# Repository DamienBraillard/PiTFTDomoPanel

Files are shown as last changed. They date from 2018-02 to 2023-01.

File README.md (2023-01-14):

# PiTFTDomoPanel
Raspberry PI + PiTFT based home automation web control panel with screen activated by PIR movement detector

This project was started so that I am able to control some basic functions of my home automation system at home. It uses a RaspberryPi with a 2.8" capacitive touch PiTFT display from Adafruit and a small PIR movement detection module.

The idea is to activate the screen only when movement is detected to avoid useless screen usage and wear when the panel is not in use. The device simply displays a web page from the home automation system.

This projects consists of many parts:
* A 3D box model to house everything
* The list of hardware needed to create the project
* The code that manages the PIR movement detector
* Setup instructions to enable the PiTFT display and setup X to display a web page in kiosk mode

## What does it look like ?
Here are some pictures of the final result:
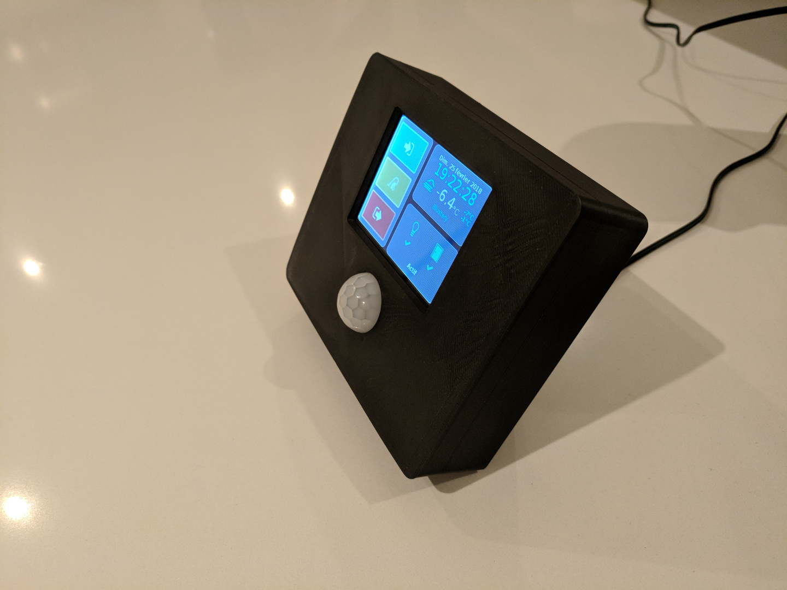
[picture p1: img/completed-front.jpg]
Front view

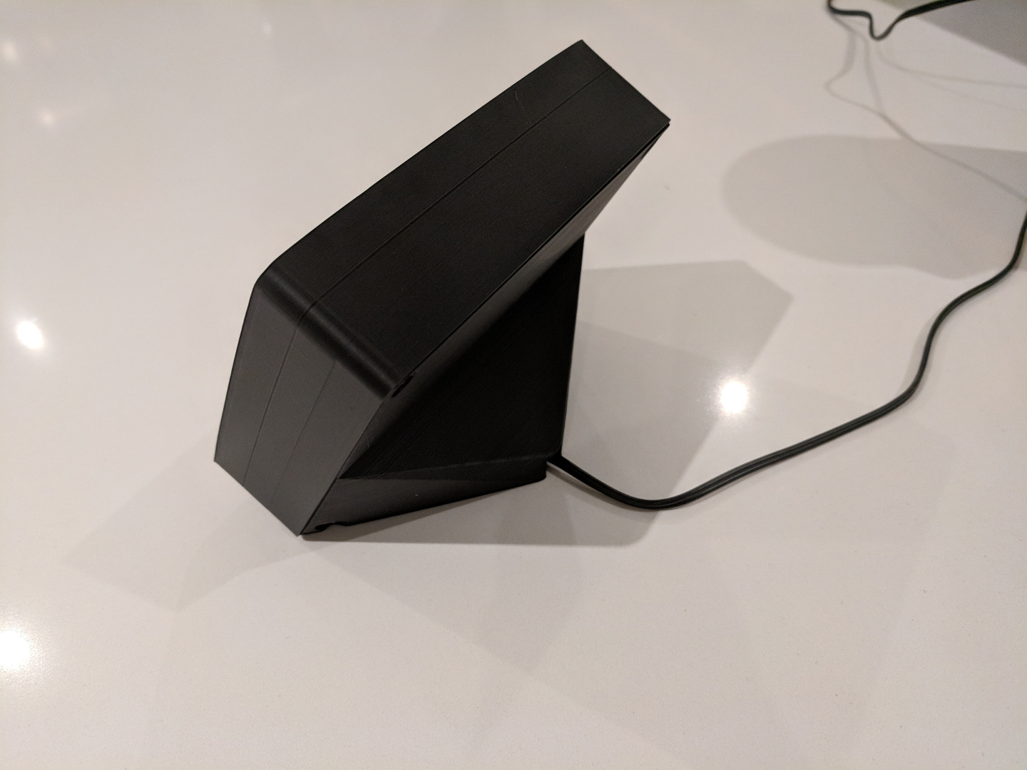
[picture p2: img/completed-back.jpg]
Back view


# Make your own
In the following sections, you will find a detailled description of the steps to make one.

## Bill of materials
To realize this project, the following components are required:
* A Raspberry PI B+ (2 or 3)
* An Adafruit PiTFT PLUS 2.8" capacitive touch TFT screen
  ([Adafruit link](https://www.adafruit.com/product/2423))
* A PIR sensor module from Adafruit or any other vendor ([Adafruit link](https://www.adafruit.com/product/189))
* A 3D printer or access to one
* Some Screws:
    * 4x M4x10mm (25mm max) with conic head to close the enclosure
    * 4x M3x5mm to tighten the PiTFT to the enclosure
    * 2x M2x5mm to tighten the PIR to the enclosure

## Wiring
The only thing to wire manually is the PIR sensor to the Raspberry Pi.
One problem to face is that the PiTFT hat connects on the Raspberry Pi taking all the GPIO pins.
The solution to that problem is to use the second male connector at the back of the PiTFT.

For that, I soldered a piece of ribbon cable to which I soldered individual cutable headers but feel free to use any other mean of wiring.
You can also solder the three cables to the PiTFT header and the RPI header. I't more definitive
but, less cumbersome than creating a custom cable like I did. If I make another one, I will take the
soldering to header approach !

To give you an idea, the PIR has three pins, Ground, VCC (+5V) and output.
Ground goes to one of the Ground pins of the Pi, VCC to a +5V pin and Output goes
to the GPIO4 of the Raspberry Pi.

To help you figure out the wiring, here is a picture of the final wiring result:
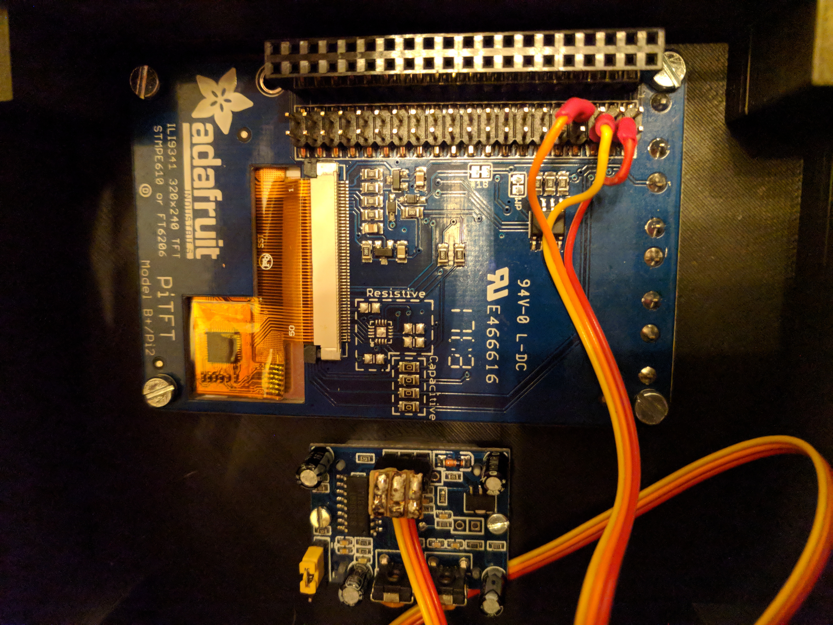
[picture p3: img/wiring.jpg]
Wiring


I cannot include a Fritzing schema here becaus it's impossible to find a schematic where the back header is visible. But it's pretty obvious from the picture above.
On the picture the collor of the cables correspond to:
* Read: VCC
* Orange: Output
* Yellow: Ground

## Installation of the RPi base system and the PiTFT
### Install raspbian
First of all, start with a fresh raspbian lite installation.
This project is based on Raspbian stretch.
Go to the [raspbian homepage](https://www.raspberrypi.org/downloads/raspbian/), download the "lite" image and follow the installation guide.

Don't forget to enable ssh and/or finetune your installation with the `raspi-config` utility.

### Configure the PiTFT hardware
Connect to the Raspberry using SSH.

Edit the file **/boot/config.txt**
```
#> sudo nano /boot/config.txt
```

Enable SPI and I2C interfaces by uncommenting the following lines. The former is required to send data to the TFT display, the later to handle the touch screen.
```
dtparam=spi=on
dtparam=i2c_arm=on
```

Then enable the overlay for the PiTFT display by adding the following lines at the end of the file.
The first line sets the communication speed to 32Mhz, reduce to 16Mhz if your screen behaves strangly. It also sets the refresh speed to 25 frames per seconds which is enough in our case.
The second line performs a screen rotation of 270° then adapts the touch screen so that it matches the display. It maches the layout of the TFT in the box created for the project but feel free to tweak this.
```
# PiTFT overlay
dtoverlay=pitft28-capacitive,speed=32000000,fps=25
dtoverlay=pitft28-capacitive,rotate=270,touch-swapxy,touch-invy
```
It is important to use two lines because there is a maximum file length of something linke 79 characters and there are too many parameters to fit within this line length limit.

Last remark, the available orientation options are:
* rotate       : Rotation of the screen (0, 90, 180 or 270)
* touch-swapxy : Swaps the X and Y axis of the touch screen
* touch-invx   : Inverses the direction of the X axis (Y axis if swapped)
* touch-invy   : Inverses the direction of the Y axis (X axis if swapped)

Save and close nano 

### Display the boot console on the PiTFT at startup
Here we will modify the kernel boot parameters so that the boot messages are displayed on the PiTFT during boot. This will also give you a login prompt in case something goes really wrong.

Edit the file **/boot/cmdline.txt**
```
#> sudo nano /boot/cmdline.txt
```

Append the following options to the startup command line (after the **bootwait** argument)
```
fbcon=map:10 fbcon=font:VGA8x8
```

Save and close nano

Reboot your Raspberry Pi and enjoy the boot messages:
```
#> sudo reboot
```

You should see the boot screen upon reboot and end up with a prompt once the boot has completed.

## Installation and configuration of the X11 server
Now that we have the TFT with it's framebuffer working, we can attack installing and setting up the application.

We will use the following software:
* X11: will be responsible for the graphical environment.
* matchbox: a minimal lightweight window manager.
* nodm: a minimal window manager
* xset: a X tool that can be used to tweak stuff like the screen saver
* unclutter: a X tool that allows to hide the mouse cursor.

### Install the X11 server and configure the PiTFT framebuffer

Install the basic x11 packages with the matchbox windows manager a browser and the nodm lightweight desktop manager.
```
#> sudo apt install x11-xserver-utils xinit matchbox nodm unclutter
```

Create a new file **/usr/share/X11/xorg.conf.d/99-pitft.conf**:
```
#> sudo nano /usr/share/X11/xorg.conf.d/99-pitft.conf
```

Enter the following content:
```
Section "Device"
  Identifier "Adafruit PiTFT"
  Driver "fbdev"
  Option "fbdev" "/dev/fb1"
EndSection
```
An important point is the use of "/dev/fb1" here. The PiTFT will settle on the framebuffer 1 as framebuffer 0
is already taken by the HDMI output.

Just for safety, ensure that the file **/usr/share/X11/xorg.conf.d/99-fbturbo.conf** does not exists. If it does, just move it to your home folder for backup.
```
sudo mv /usr/share/X11/xorg.conf.d/99-fbturbo.conf ~
```
You are free to delete it.

## Install the frontend Python application
The application will be installed in the home directory of the user `pi`.

### Install the application files

First, create a new directory for the program and copy the python application:
```
#> mkdir ~/domo-panel
```

Copy the files from the `frontend` git folder in `~/domo-panel`

Create the python virtual environment:
```
#>sudo apt install -y python3-venv libsdl2-2.0-0 libsdl2-ttf-2.0-0 libsdl2-image-2.0-0
#>python3 -m venv ~/domo-panel//venv
#>~/domo-panel/venv/bin/pip3 install -r ~/domo-panel//requirements.txt
```

### Setup nodm display manager

Edit the **/etc/default/nodm** file
```
#> sudo nano /etc/default/nodm
```

Ensure that the following values are set as below
```
NODM_ENABLED=true
NODM_USER=pi
```

### Create the X11 session startup file

Next step will tell the system what should be done when the graphical environment
starts. This is the place where the browser will be started.

Create the file **/home/pi/.xsession** and open it using nano

```
#> nano ~/.xsession
```

And enter the following content:
``` bash
#!/bin/bash

# disable the DPMS (Energy Star) features
xset -dpms

# disable the screen saver
xset s off

# hide the mouse cursor when not moving
unclutter -idle 0 &

# Run the window manager !
matchbox-window-manager -use_titlebar no &

# Starts the application
~/domo-panel/venv/bin/python ~/domo-panel/main.py
```

Then change the permissions of the file to **700**:
```
#> chmod 700 /.xsession
```

### Enable boot to the graphical environment
As the lite version of Raspbian has been installed, it will boot to console by default.
In order to boot into graphical mode, it's necessary to tell **systemctl** to boot
to the graphical target.

To do so, type in the following command: 
```
#> sudo systemctl set-default graphical.target
```

Everything should be working now. The next thing to do is to reboot.
The raspberry should reboot in graphical mode with the Midori browser displaying
the web page in full screen mode.
```
#> sudo reboot
```

## Activating the PIR sensor to activate the screen when a movement is detected
One thing left to do is install and enable the python script that manages the IR movement detector. When movement is detected, the script will enable the script for a configurable duration and then disable it again.

### Installing required python and packages
The script requires **python3.x** and the **RPi.GPIO** python module.
Make sure these are installed using the following command:
```
#> sudo apt install python3 python3-rpi.gpio
```

### Installing the python script and the startup service
It's better to install the python script at a usual location for executables.

Copy the content of he `src/pir` folder to the `/home/pi` home directory of your Raspberry Pi.

Make the **install.sh** script executable and run it:
```
#> chmod -v 755 install.sh
#> ./install.sh
```

This script does the following:
1. Creates the folder */usr/local/bin/pirscreen**
1. Copies the **pirscreenmanager.py** to that folder
1. Makes the copied script executable
1. Copies the **pirscreen.sh** RC script to the **/etc/init.d** folder.
1. Eakes the copied RC script executable
1. Enables the script to run at boot

By default:
* The screen stays on for 30 seconds
* The X display is ':0'
* Log file located at **/tmp/pirscreenmanager.log**

To change any of these options, the **DAEMON_OPTS** variable in the **/etc/init.d/pirscreen.sh** file must be modified.
To do so, edit the file with nano and change it's content:
```
#> sudo nano /etc/init.d/pirscreen.sh
```

## Printing the case and assembling
The case that can be seen in the images is available in the `src/enclosure` folder.

The two `.stl` files are provided ready to print.

### Modification of the model before printing
In the case where you whish to change the model, open the source `.scad` with [OpenScad](http://www.openscad.org/).

The file starts with all parameters and two modules, one for each part of the box:
* front_part : The module to render the front part of the box.
* back_part  : The module to render the back part of the box.

Before exporting the STL file, don't forget to leave only the part to export uncommented at the end of the file and do a render (F6).

### Assembling
To assemble the electronics and the 3D printed box, some extra screws are needed:
    * 4x M4x10mm (25mm max) with conic head
    * 4x M3x5mm 
    * 2x M2x5mm

To assemble:
1. Separate the PiTFT board from the Raspberry Pi.
1. Screw the PiTFT to the front of the case using the four M3 screws.
1. Screw the PIR to the front of the case using the M2 screws.
1. Plug the MicroUSB power to the PI
1. Reassemble the Raspberry Pi on top of the PiTFT board
1. Power up to check that everything still works.
1. Pass the power cable in the channel at the bottom of the back of the case.
1. Assemble the back and the front using the four M4 screws.

Here are pictures of the final assembly:
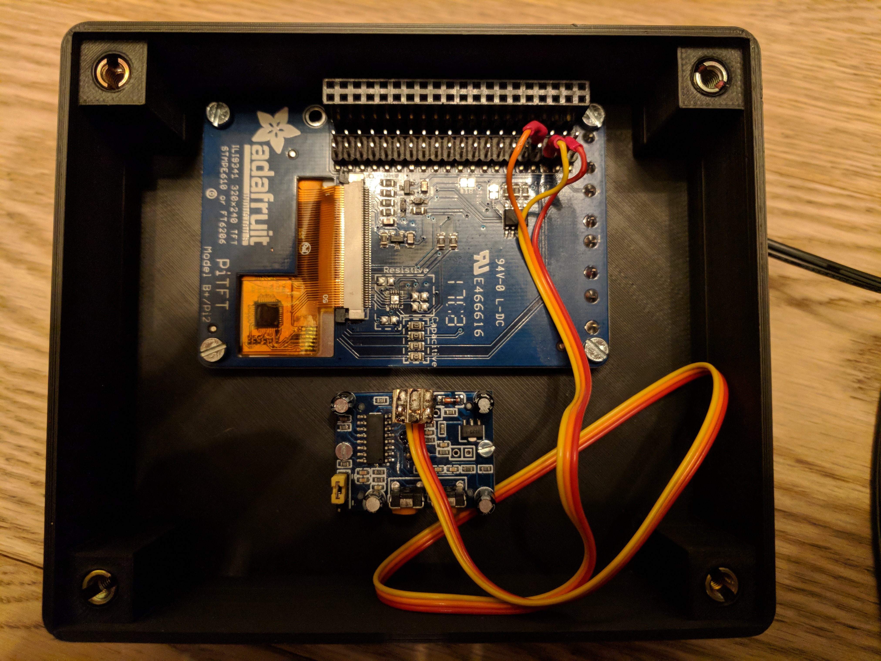
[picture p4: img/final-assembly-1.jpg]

Front view

Note that on the pictures, I used special metal bolts fused into the plastic. I removed these from the 3D model because they don't bring extra value and are quite hard to find. So don't panic if your model does not have these. In the revised version, the screws go directly into the plastic !

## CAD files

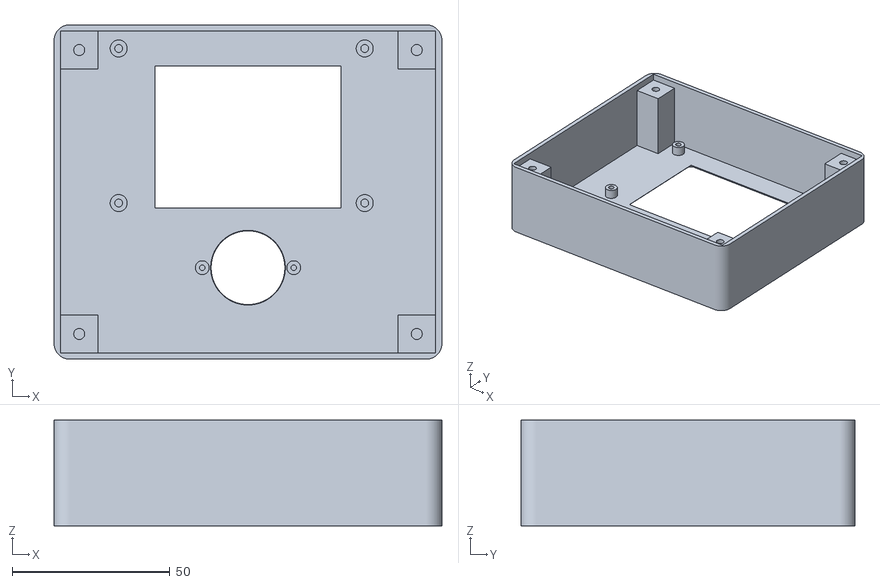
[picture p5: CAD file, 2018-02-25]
src/enclosure/PiTFTDomoPanel-Front.stl
123.0 x 106.0 x 33.5

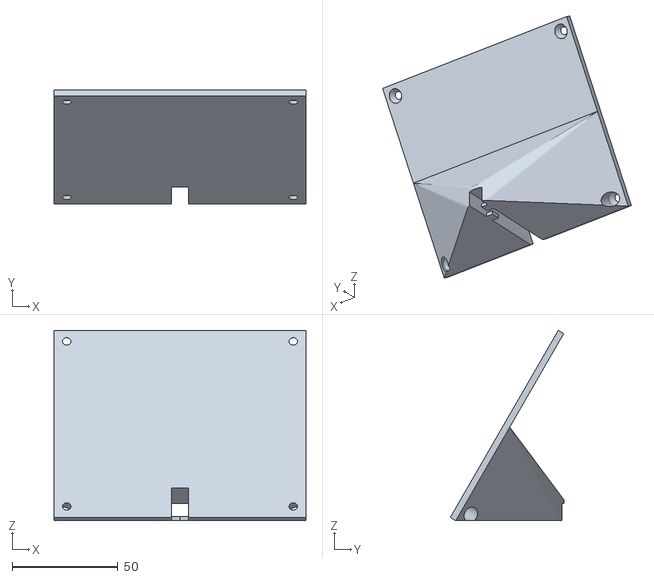
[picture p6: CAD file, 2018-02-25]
src/enclosure/PiTFTDomoPanel-Back.stl
119.0 x 53.6 x 89.8

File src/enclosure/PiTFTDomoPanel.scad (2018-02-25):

/*******************************************************************************
* ENCLOSURE FOR RASPBERRY PI + PITFT + PIR SENSOR
* ------------------------------------------------------------------------------
* Copyright Damien Braillard, Switzerland
* ------------------------------------------------------------------------------
* Bill of materials:
*   - 4 M3 with 5mm long thread screws to hold the screen
*   - 2 M2 with 5mm long thread screws to hold the PIR
*   - 4 M4 with conic head to tighten he back part with the front part
*******************************************************************************/

// =============================================================================
// Defines all the measurements
// =============================================================================
tft_width           = 59;   // Width of the TFT display area
tft_height          = 45;   // Height of the TFT display area
tft_thick           =  4.5; // Thickness of the TFT display module (without board)
tft_pcb_thick       =  1;   // Thickness of the TFT PCB
tft_margin_left     = 11;   // Left distance from RPi board edge to TFT display area edge
tft_margin_right    = 15;   // Right distance from RPi board edge to TFT display area edge
tft_margin_top      =  9;   // Top distance from RPi board edge to TFT display area edge
tft_margin_bottom   =  3;   // Bottom distance from RPi board edge to TFT display area edge
tft_screw_diam      =  3;   // Diameter of the TFT attachement screw thread
tft_screw_height    =  5;   // Length of the TFT attachement screw thread
tft_hole_offsets    = [     // Offsets [X,Y] of holes in TFT board relative to top-left corner
                       [3.5, 3.5],
                       [81.5, 3.5],
                       [3.5, 52.5],
                       [81.5, 52.5]
                     ];

pi_width            = 85;   // Width of the RPi board
pi_height           = 56;   // Height of the RPi board
pi_thick            = 19;   // Thickness of the PI + TFT board (without the display)

pir_lens_diam       = 23;   // Diameter of the PIR lens
pir_lens_thick      =  3.5; // Thickness of the PIR lens base
pir_pcb_thick       =  1.5; // Thickness of the PIR board
pir_screw_height    =  5;   // Length of the PIR attachement screws thread
pir_screw_diam      =  2;   // Diameter of the PIR attachement screws thread
pir_hole_offsets    = [     // Offsets(X,Y) of PIR holes relative to PIR center (space between holes = 29mm)
                        -14.5,
                        14.5
                      ];
pir_height          = 24;   // Height of the PIR module
pir_width           = 33;   // Width of the PIR module
pir_spacing         =  5;   // Distance between the PIR and the PI board

screw_thread_diam   =  4;   // Diameter of the body screw threads
screw_head_diam     =  7;   // Diameter of the body screw head
screw_head_thick    =  2.5; // Thickness of the body screw head
screw_pillar_side   = 12;   // Side of the square pillars that hold the bolts.

cable_diam          =  4;   // Diameter of the USB cable

body_top_margin     =  2;   // Clearance on top of the last component
body_bottom_margin  = 20;   // Clearance before the firtst compnent can be found
body_back_margin    = 5;    // Clearance at the back of the PI board
body_angle          = 60;   // Inclinaison angle of the body in degrees

back_walls          =  3;   // Thickness of the back plate + stand walls
front_walls         =  2;   // Thickness of the front panel walls 
body_in_width       = tft_width + (2 * 30);        // 28mm + margin each side of the TFT
body_in_height      = pi_height + pir_height + body_bottom_margin + body_top_margin;
body_in_thick       = pi_thick + tft_thick + body_back_margin;

echo("Body In Width =",body_in_width);
echo("Body In Height =",body_in_height);
echo("Body In Thick =",body_in_thick);

$fn=100;

// Calculated values
_pi_top          = body_in_height - body_top_margin;
_pi_left         = ((body_in_width - tft_width) / 2) - tft_margin_right; // Correct because screen flipped down
_tft_top         = body_in_height - body_top_margin - tft_margin_top;
_tft_left        = (body_in_width - tft_width)/2;
_pir_center_top  = body_in_height - body_top_margin - pi_height - pir_spacing - pir_height / 2;
_pir_center_left = body_in_width / 2;

// Utiliy modules
module rounded_cube(size, r=5) {

  linear_extrude(height=size[2])
  hull() {
    translate([r, r])
      circle(r=r);
    translate([size[0]-r, r])
      circle(r=r);
    translate([r, size[1]-r])
      circle(r=r);
    translate([size[0]-r, size[1]-r])
      circle(r=r);    
  }
  
}

// Renders the front part
module front_part() {

    difference() {
      translate([-front_walls, -front_walls, -front_walls])
        rounded_cube([body_in_width+front_walls*2, body_in_height+front_walls*2, body_in_thick+front_walls+back_walls]);
      
      // Main opening
      cube([body_in_width, body_in_height, body_in_thick+back_walls+1]);
      
      // Hole for PIR sensor
      translate([_pir_center_left, _pir_center_top, 0])
        sphere(d=pir_lens_diam*1.03);
      
      // Hole for screen
      translate([_tft_left, _tft_top-tft_height, -(front_walls*2-.005)])
        minkowski() {
          cube([tft_width, tft_height, front_walls]);
          cylinder(r1=front_walls, r2=0, h=front_walls);
        } 
    }

    // TFT fixation holes
    for(i = tft_hole_offsets) {
      translate([_pi_left + pi_width - i[0], _pi_top - i[1], 0]) {
        difference() {
          cylinder(d=tft_screw_diam+2.4, h=tft_thick-.4);
          translate([0, 0, tft_thick+tft_pcb_thick-tft_screw_height-.5])
            cylinder(d=tft_screw_diam-.5, h=tft_thick+1);
        }
      }
    }
    
    // PIR fixation holes
    for(i = pir_hole_offsets) {
      translate([_pir_center_left + i, _pir_center_top, 0])
        difference() {
          cylinder(d=pir_screw_diam+2.4, h=pir_lens_thick-.4);
          translate([0, 0, pir_lens_thick+pir_pcb_thick-pir_screw_height-.5])
            cylinder(d=pir_screw_diam-.25, h=pir_screw_height+1);
        }      
    }
    
    // Screw holders
    for(x = [0, body_in_width-screw_pillar_side], y = [0, body_in_height-screw_pillar_side]) {
      translate([x, y, 0])
      difference() {
        cube([screw_pillar_side, screw_pillar_side, body_in_thick]);
        translate([screw_pillar_side/2, screw_pillar_side/2, 0])
          cylinder(d=screw_thread_diam-.5, h=body_in_height+2);
      }
    }
  
}

// Renders the back part
module back_part() {
  base_depth = cos(body_angle)*body_in_height;
  difference() {
    union() {
      // Main plate
      rotate([body_angle, 0, 0]) { 
        cube([body_in_width, body_in_height, back_walls]);        
      }
      
      // Foot
      hull() {
        translate([body_in_width/2, base_depth-10, 0])
          cylinder(d=20, h=10);
        rotate([body_angle, 0, 0]) {
          cube([body_in_width, body_in_height/2, back_walls]);
        }
      }
    }
    
    // == SCREW HOLES == 
    rotate([body_angle, 0, 0]) { 
      for(x = [screw_pillar_side/2, body_in_width-screw_pillar_side/2],
          y = [screw_pillar_side/2, body_in_height-screw_pillar_side/2]) {
        translate([x, y, -.005]) {
          cylinder(d=screw_thread_diam, h=back_walls+.01);
          cylinder(d1=screw_head_diam+.5, d2=screw_thread_diam, h=screw_head_thick+.5);
          translate([0, 0, -30])
            cylinder(d=screw_head_diam+.5, h=30.001);
        }
      }    
    }

    // == CABLE OPENING ==
    channel_width = cable_diam*2;
    peg_center    = base_depth*3/4;
    peg_thick     = 2;
    peg_len       = 5;
    peg_spacing   = cable_diam;
    {
      // Plate Cable opening
      rotate([body_angle, 0, 0])
      translate([(body_in_width-channel_width)/2, -.1, -20])
        cube([channel_width, cable_diam*4+.1, back_walls+20.1]);
      // Foot channel
      translate([(body_in_width-channel_width)/2, 0, -.01]) {
        // Main channel
        translate([0, 0, peg_thick-.1])
          cube([channel_width, base_depth, cable_diam+2.1]);
        // Front main opening 
        cube([channel_width, peg_center-peg_len-peg_spacing/2, peg_thick]);
        // Front peg
        translate([0, peg_center-peg_len-peg_spacing/2-.1, -.1])
          cube([channel_width/2, peg_len+.2, peg_thick+.1]);
        // Space between pegs 
        translate([0, peg_center-peg_spacing/2, 0])
          cube([channel_width, peg_spacing, peg_thick]);
        // Back peg
        translate([channel_width/2, peg_center+peg_spacing/2-.1, -.1])
          cube([channel_width/2, peg_len+.2, peg_thick+.1]);
        // Back main opening
        translate([0, peg_center+peg_len+peg_spacing/2, 0])
          cube([channel_width, base_depth-peg_center-peg_len-peg_spacing/2, peg_thick]);
      }
    }
  }  
}
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

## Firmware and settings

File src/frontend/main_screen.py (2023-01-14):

import pygame
from pygame import Rect
import pygame_gui
import pygame_gui.elements as elements
from screen import Screen
from communicator import Communicator, HouseMode
from typing import Union, Type
from datetime import datetime


class MainScreen(Screen):
    def __init__(self, surface: pygame.Surface, communicator: Communicator):
        super().__init__(surface)
        self.__communicator = communicator

    def _on_create_controls(self, manager: pygame_gui.UIManager):
        # panels
        elements.UIPanel(relative_rect=Rect((0, 0), (320, 60)),
                         starting_layer_height=1,
                         manager=manager)
        # elements.UIPanel(relative_rect=Rect((0, 70), (110, 170)),
        #                  starting_layer_height=1,
        #                  manager=manager)
        elements.UIPanel(relative_rect=Rect((120, 70), (200, 170)),
                         starting_layer_height=1,
                         manager=manager)

        # Top labels
        self.__time_label = elements.UILabel(relative_rect=Rect((5, 5), (115, 50)),
                                             text="-",
                                             manager=manager,
                                             object_id="@time-label")
        self.__date_labels = [
            elements.UILabel(relative_rect=Rect((130, 6), (60, 16)),
                             text="-",
                             manager=manager,
                             object_id="@date-label"),
            elements.UILabel(relative_rect=Rect((130, 22), (60, 16)),
                             text="-",
                             manager=manager,
                             object_id="@date-label"),
            elements.UILabel(relative_rect=Rect((130, 38), (60, 16)),
                             text="-",
                             manager=manager,
                             object_id="@date-label")
        ]

        self.__temp_label = elements.UILabel(relative_rect=Rect((195, 5), (120, 50)),
                                             text="°C",
                                             manager=manager,
                                             object_id="@temp-label")

        # Mode buttons
        self.__present_button = elements.UIButton(relative_rect=Rect((0, 70), (110, 50)),
                                                  text='Présent',
                                                  manager=manager,
                                                  object_id="@button_present")
        self.__away_button = elements.UIButton(relative_rect=Rect((0, 130), (110, 50)),
                                               text='Absent',
                                               manager=manager,
                                               object_id="@button_away")
        self.__cleaning_button = elements.UIButton(relative_rect=Rect((0, 190), (110, 50)),
                                                   text='Ménage',
                                                   manager=manager,
                                                   object_id="@button_cleaning")

        # Status for doors and lights
        self.__lights_icon_pos = (151, 90)
        self.__doors_icon_pos = (246, 90)

        self.__lights_label_ok = elements.UILabel(relative_rect=Rect((130, 160), (85, 30)),
                                                  text="-",
                                                  manager=manager,
                                                  object_id="@status-label-ok")
        self.__lights_label_warning = elements.UILabel(relative_rect=Rect((130, 160), (85, 30)),
                                                       text="-",
                                                       manager=manager,
                                                       object_id="@status-label-warning")
        self.__lights_label_error = elements.UILabel(relative_rect=Rect((130, 160), (85, 30)),
                                                     text="-",
                                                     manager=manager,
                                                     object_id="@status-label-error")

        self.__doors_label_ok = elements.UILabel(relative_rect=Rect((225, 160), (85, 30)),
                                                 text="-",
                                                 manager=manager,
                                                 object_id="@status-label-ok")
        # self.__doors_label_warning = elements.UILabel(relative_rect=Rect((225, 160), (85, 30)),
        #                                               text="-",
        #                                               manager=manager,
        #                                               object_id="@status-label-warning")
        self.__doors_label_error = elements.UILabel(relative_rect=Rect((225, 160), (85, 30)),
                                                    text="-",
                                                    manager=manager,
                                                    object_id="@status-label-error")

        # Current mode label
        self.__mode_label_present = elements.UILabel(relative_rect=Rect((125, 205), (190, 30)),
                                                     text="Présent",
                                                     manager=manager,
                                                     object_id="@mode-label-present")
        self.__mode_label_away = elements.UILabel(relative_rect=Rect((125, 205), (190, 30)),
                                                  text="Absent",
                                                  manager=manager,
                                                  object_id="@mode-label-away")
        self.__mode_label_cleaning = elements.UILabel(relative_rect=Rect((125, 205), (190, 30)),
                                                      text="Ménage",
                                                      manager=manager,
                                                      object_id="@mode-label-cleaning")

        # images
        self.__image_lights_ok = pygame.image.load("assets/images/lights-ok.png");
        self.__image_lights_warning = pygame.image.load("assets/images/lights-warning.png");
        self.__image_lights_error = pygame.image.load("assets/images/lights-error.png");
        self.__image_doors_ok = pygame.image.load("assets/images/doors-ok.png");
        # self.__image_doors_warning = pygame.image.load("assets/images/doors-warning.png");
        self.__image_doors_error = pygame.image.load("assets/images/doors-error.png");

    def _on_activated(self, previous_screen: Union[Type[Screen], None]):
        pass

    def _on_deactivated(self):
        pass

    def _on_event(self, event: pygame.event.Event) -> Union[Type[Screen], None]:
        if event.type == pygame.USEREVENT and event.user_type == pygame_gui.UI_BUTTON_PRESSED:
            if event.ui_element == self.__present_button:
                self.__communicator.set_house_mode(HouseMode.PRESENT)
            elif event.ui_element == self.__away_button:
                self.__communicator.set_house_mode(HouseMode.AWAY)
            elif event.ui_element == self.__cleaning_button:
                self.__communicator.set_house_mode(HouseMode.CLEANING)
        return None

    def _on_draw(self, surface: pygame.Surface):
        super()._on_draw(surface)

        on_lights = len(self.__communicator.current_status.lights_on)
        if on_lights == 0:
            surface.blit(self.__image_lights_ok, self.__lights_icon_pos)
        elif on_lights == 1:
            surface.blit(self.__image_lights_warning, self.__lights_icon_pos)
        else:
            surface.blit(self.__image_lights_error, self.__lights_icon_pos)

        open_doors = len(self.__communicator.current_status.doors_opened)
        if open_doors == 0:
            surface.blit(self.__image_doors_ok, self.__doors_icon_pos)
        else:
            surface.blit(self.__image_doors_error, self.__doors_icon_pos)

    def _on_loop(self):
        self.__time_label.set_text(datetime.now().strftime("%H:%M"))
        self.__date_labels[0].set_text(datetime.now().strftime("%d"))
        self.__date_labels[1].set_text(datetime.now().strftime("%b"))
        self.__date_labels[2].set_text(datetime.now().strftime("%Y"))
        self.__temp_label.set_text(f"{self.__communicator.current_status.outside_temperature}°C")

        on_lights = len(self.__communicator.current_status.lights_on)
        self.__lights_label_ok.visible = on_lights == 0
        self.__lights_label_ok.set_text(str(on_lights))
        self.__lights_label_warning.visible = on_lights == 1
        self.__lights_label_warning.set_text(str(on_lights))
        self.__lights_label_error.visible = on_lights > 1
        self.__lights_label_error.set_text(str(on_lights))

        open_doors = len(self.__communicator.current_status.doors_opened)
        self.__doors_label_ok.visible = open_doors == 0
        self.__doors_label_ok.set_text(str(open_doors))
        self.__doors_label_error.visible = open_doors != 0
        self.__doors_label_error.set_text(str(open_doors))

        mode = self.__communicator.current_status.house_mode
        self.__mode_label_present.visible = mode == HouseMode.PRESENT
        self.__mode_label_away.visible = mode == HouseMode.AWAY
        self.__mode_label_cleaning.visible = mode == HouseMode.CLEANING

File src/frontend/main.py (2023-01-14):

import pygame
import sys
import locale
import logging
import logging.config
from typing import Optional
import config
from screen import Screen
from main_screen import MainScreen
from communicator import Communicator
from eedomus_box import EedomusBoxInterface
from tft_manager import TftManager


class Frontend:
    def __init__(self):
        # Initialize PyGame
        pygame.init()
        self.__clock = pygame.time.Clock()

        pygame.display.set_caption('Domo panel')
        self.__window_surface: pygame.Surface = pygame.display.set_mode((320, 240))

        # Configure the locale
        if config.LOCALE != "":
            locale.setlocale(locale.LC_ALL, config.LOCALE)

        # Setup the screen management & home automation box communication
        self.__tft_manager = TftManager()
        self.__communicator = Communicator(EedomusBoxInterface())

        # Setup the initial screen
        self.__screen: Optional[Screen] = MainScreen(surface=self.__window_surface,
                                                     communicator=self.__communicator)
        self.__screen.activate(None)

    def run(self):
        """ Executes the PyGame main loop """

        is_running = True
        while is_running:
            time_delta = self.__clock.tick(30) / 1000.0

            # Enable/Disable the screen
            tft_state_changed = self.__tft_manager.update()

            # Start the communicator when the screen goes ON, and stop it when the screen goes OFF
            if tft_state_changed:
                if self.__tft_manager.is_on:
                    self.__communicator.start()
                else:
                    self.__communicator.stop()

            # Handles events
            for event in pygame.event.get():
                if event.type == pygame.QUIT:
                    is_running = False
                    break
                elif event.type == pygame.KEYDOWN:
                    if event.key == pygame.K_ESCAPE:
                        is_running = False
                        break
                    elif event.key == pygame.K_a:
                        self.__tft_manager.set_forced_mode(None)
                    elif event.key == pygame.K_e:
                        self.__tft_manager.set_forced_mode(True)
                    elif event.key == pygame.K_d:
                        self.__tft_manager.set_forced_mode(False)

                if self.__screen is not None:
                    self.__screen.handle_event(event)

            # Handles screen
            if self.__screen is not None:
                next_screen = self.__screen.run(time_delta)
                if next_screen is not None:
                    self.__screen.deactivate()
                    next_screen.activate(self.__screen)
                    self.__screen = next_screen

            # Update the PyGame display
            pygame.display.update()

        # Cleanup on exit
        self.__screen.deactivate()
        self.__communicator.stop()


if __name__ == "__main__":
    try:
        # Configure the logging
        logging.config.dictConfig(config.LOGGING_CONFIG)

        # Run the frontend
        frontend = Frontend()
        frontend.run()
    except Exception:
        logging.exception(f"Fatal error occurred. The application has crashed !")

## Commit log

2018-02-25 Added enclosure files
    [PiTFTDomoPanel-Back.stl, PiTFTDomoPanel-Front.stl, PiTFTDomoPanel.scad]
2018-02-28 Added assembly and wiring instructions
2018-02-28 Added color info for wiring
2021-02-28 Fix: tft_manager was buggy
    [tft_manager.py]
2021-03-14 Fix: Communicator was not started at first screen ON
    [main.py, tft_manager.py]
2021-04-10 Fix communicator and allow for configurable timings
    The thread was not re-created when started after a stop operation
    Add configuration for refresh timings
    [communicator.py, config.py]
2021-04-10 Allow force tft on/off for debug and add exit key (ESC)
    Supported key presses:
    ESC: Terminates app
    A: Set TFT to AUTO
    E: Set TFT to forced ON (enabled)
    D: Set TFT to Forced OFF (disabled)
2023-01-14 Reduce framerate
